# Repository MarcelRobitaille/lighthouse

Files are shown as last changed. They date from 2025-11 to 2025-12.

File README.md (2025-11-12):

# Lighthouse

> Lighthouse is a PCB that controls lights in my house.

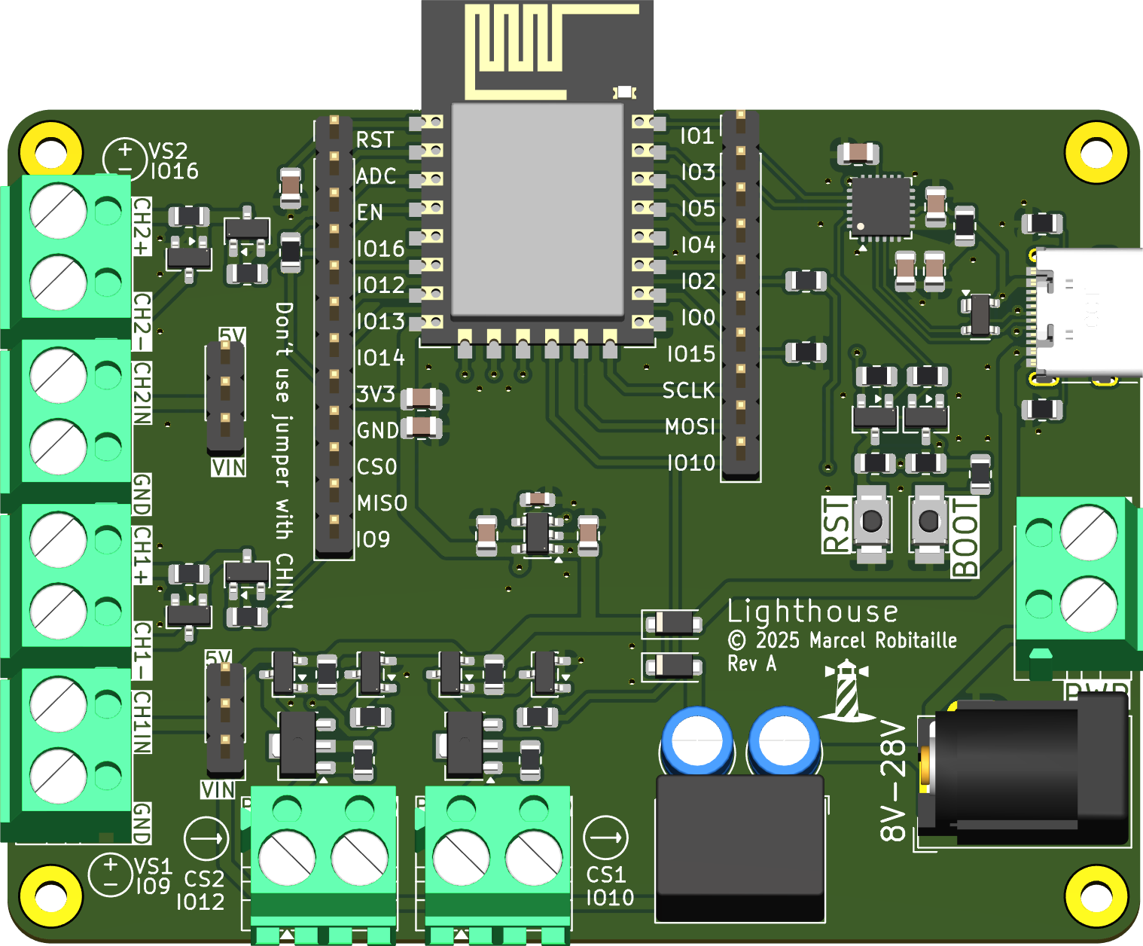
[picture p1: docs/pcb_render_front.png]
3D Render of the PCB


## Features

- ESP8266 module (works with ESPHome)
- Two constant voltage outputs and two constant current outputs
- Powered from USB-C, barrel, or screw terminal
- Voltage outputs can be powered separately, or from global USB/barrel/screw terminal

It's doesn't have to be for lighting, but any small load you wish to switch remotely.

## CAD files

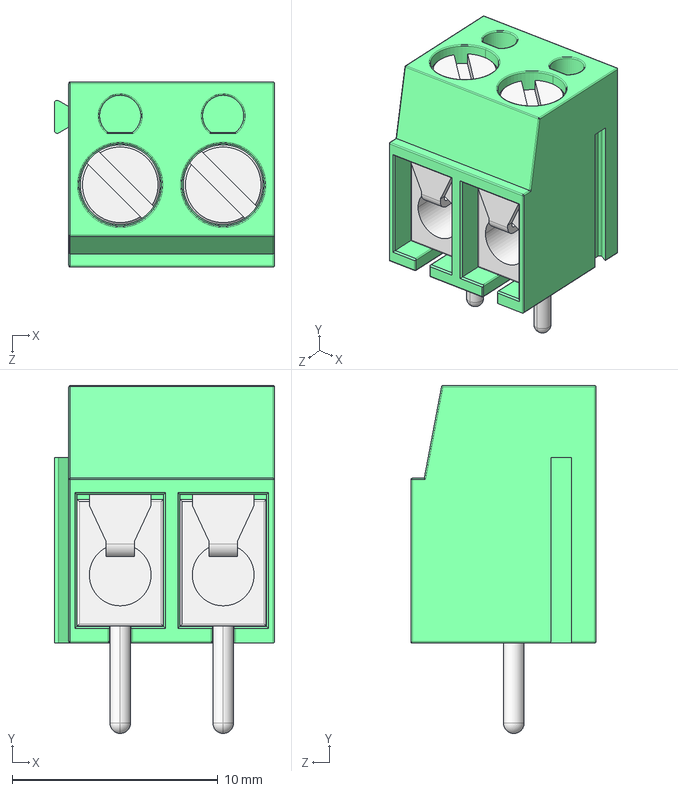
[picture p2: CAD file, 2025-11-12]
3d/TB0010-500-02GR.stp
10.7 x 16.9 x 9.00 mm

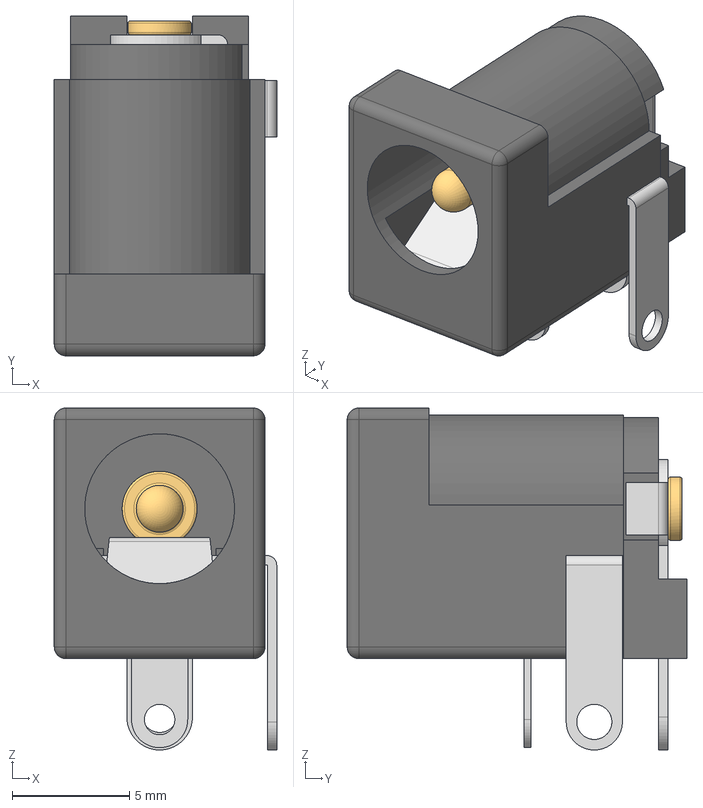
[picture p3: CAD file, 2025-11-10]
3d/694106301002 (rev1).stp
9.50 x 14.5 x 14.6 mm
6941xx301002
694106301002_PinContact
6941xx301002_Back
6941xx301002_PinContact2
6941xx301002_PinLame
6941xx301002_PinBis

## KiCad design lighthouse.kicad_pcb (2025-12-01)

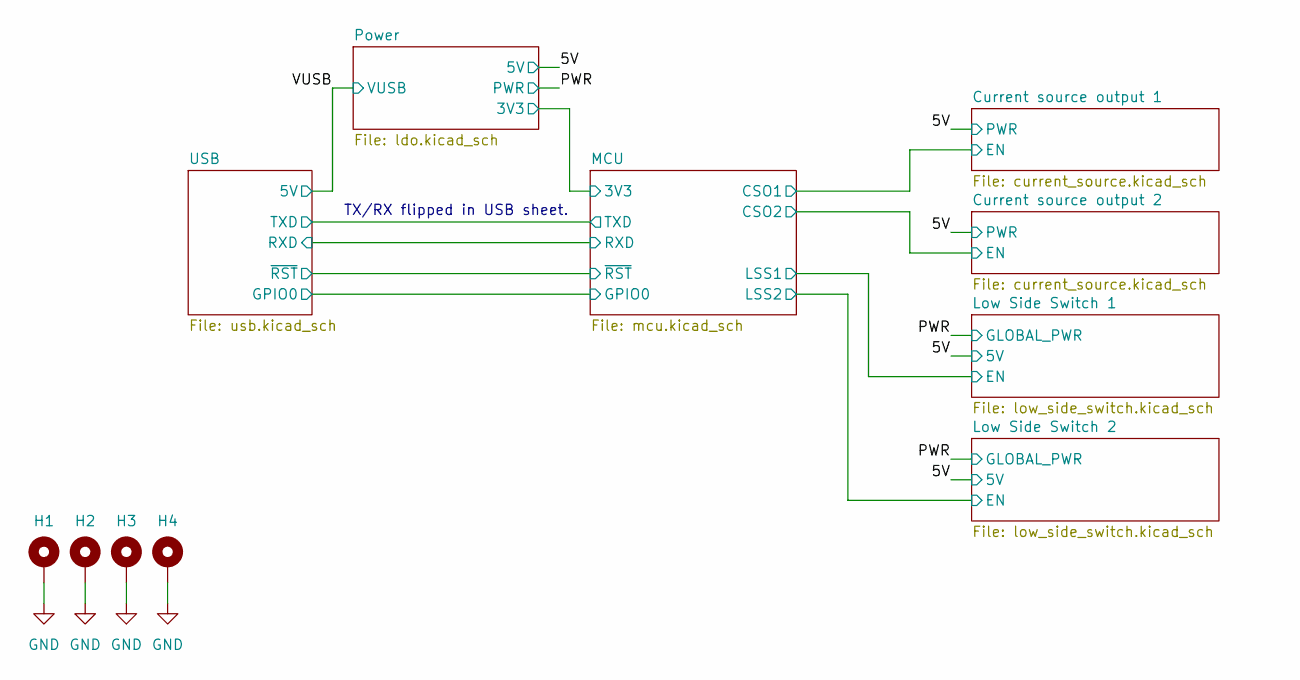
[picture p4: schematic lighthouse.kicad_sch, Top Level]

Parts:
H1, H2, H3, H4: MountingHole_Pad; MountingHole_2.2mm_M2_Pad

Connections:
GND: H1.1, H2.1, H3.1, H4.1; also elsewhere on the board

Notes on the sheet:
TX/RX flipped in USB sheet.

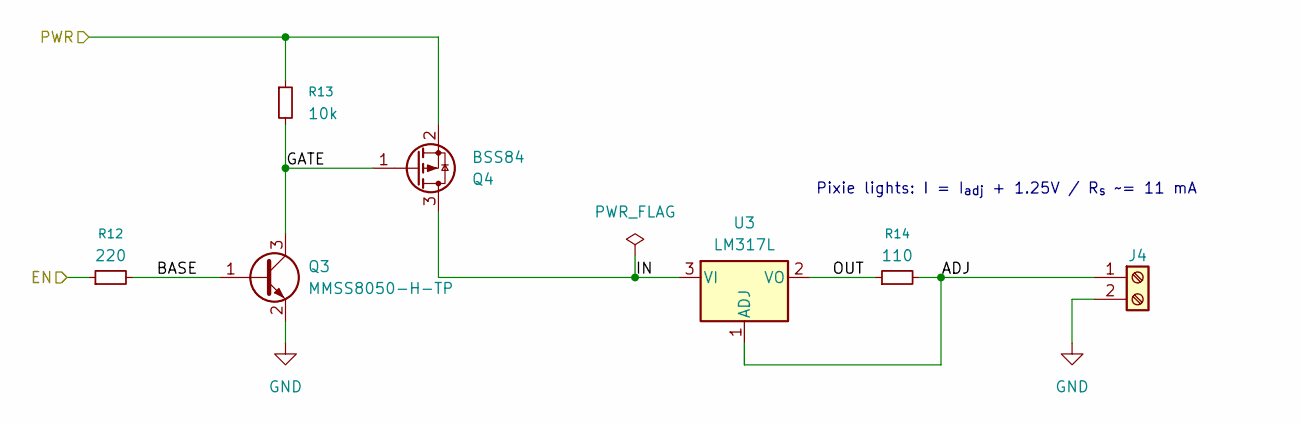
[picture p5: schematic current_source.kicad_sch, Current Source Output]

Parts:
J4: TB0010-500-02GR; TerminalBlock_TB0010-500-02GR_1x02_P5.00mm
Q3: MMSS8050-H-TP; SOT-23-3; MPN MMSS8050-H-TP; LCSC Part Number C2891804
Q4: BSS84; SOT-23; MPN BSS84PH6327XTSA2; Digikey Part Number BSS84PH6327XTSA2CT-ND
R12: 220; R_0805_2012Metric; MPN CRCW0805220RJNEA; Mouser Part Number 71-CRCW0805220RJNEA
R13: 10k; R_0805_2012Metric; Tolerance 5 %; MPN CRCW080510K0JNEAC; Mouser Part Number 71-CRCW080510K0JNEAC
R14: 110; R_0805_2012Metric; Tolerance 1%; MPN CRCW0805110RFKEA; Mouser Part Number 71-CRCW0805-110-E3
U3: LM317L; SOT-89-3; MPN LM317LCPK; Mouser Part Number 595-LM317LCPK

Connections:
/5V: Q4.2 (S), R13.1; also elsewhere on the board
/Current source output 2/ADJ: J4.1, R14.2, U3.1 (ADJ)
/Current source output 2/BASE: Q3.1 (B), R12.2
/Current source output 2/GATE: Q3.3 (C), Q4.1 (G), R13.2
/Current source output 2/IN: Q4.3 (D), U3.3 (VI)
/Current source output 2/OUT: R14.1, U3.2 (VO)
/MCU/CSO2: R12.1; also elsewhere on the board
GND: J4.2, Q3.2 (E); also elsewhere on the board

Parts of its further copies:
J7: TB0010-500-02GR; TerminalBlock_TB0010-500-02GR_1x02_P5.00mm
Q5: MMSS8050-H-TP; SOT-23-3; MPN MMSS8050-H-TP; LCSC Part Number C2891804
Q6: BSS84; SOT-23; MPN BSS84PH6327XTSA2; Digikey Part Number BSS84PH6327XTSA2CT-ND
R15: 220; R_0805_2012Metric; MPN CRCW0805220RJNEA; Mouser Part Number 71-CRCW0805220RJNEA
R16: 10k; R_0805_2012Metric; Tolerance 5 %; MPN CRCW080510K0JNEAC; Mouser Part Number 71-CRCW080510K0JNEAC
R17: 110; R_0805_2012Metric; Tolerance 1%; MPN CRCW0805110RFKEA; Mouser Part Number 71-CRCW0805-110-E3
U6: LM317L; SOT-89-3; MPN LM317LCPK; Mouser Part Number 595-LM317LCPK

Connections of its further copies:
/5V: Q6.2 (S), R16.1; also elsewhere on the board
/Current source output 1/ADJ: J7.1, R17.2, U6.1 (ADJ)
/Current source output 1/BASE: Q5.1 (B), R15.2
/Current source output 1/GATE: Q5.3 (C), Q6.1 (G), R16.2
/Current source output 1/IN: Q6.3 (D), U6.3 (VI)
/Current source output 1/OUT: R17.1, U6.2 (VO)
/MCU/CSO1: R15.1; also elsewhere on the board
GND: J7.2, Q5.2 (E); also elsewhere on the board

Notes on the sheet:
Pixie lights: I = I_{adj} + 1.25V / R_{s} ~= 11 mA

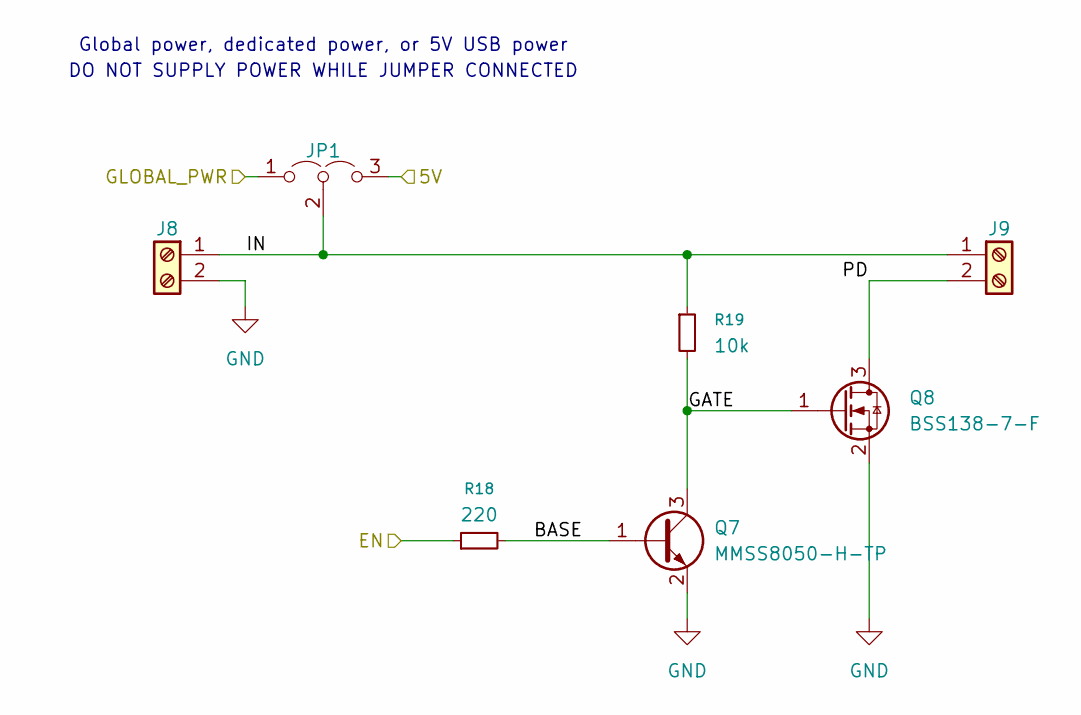
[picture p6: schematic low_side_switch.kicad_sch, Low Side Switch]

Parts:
J8, J9: TB0010-500-02GR; TerminalBlock_TB0010-500-02GR_1x02_P5.00mm
JP1: Jumper_3_Open; PinHeader_1x03_P2.54mm_Vertical
Q7: MMSS8050-H-TP; SOT-23-3; MPN MMSS8050-H-TP; LCSC Part Number C2891804
Q8: BSS138-7-F; SOT-23; MPN BSS138-7-F; Digikey Part Numbr BSS138-FDICT-ND
R18: 220; R_0805_2012Metric; MPN CRCW0805220RJNEA; Mouser Part Number 71-CRCW0805220RJNEA
R19: 10k; R_0805_2012Metric; Tolerance 5 %; MPN CRCW080510K0JNEAC; Mouser Part Number 71-CRCW080510K0JNEAC

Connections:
/5V: JP1.3 (B); also elsewhere on the board
/Low Side Switch 2/BASE: Q7.1 (B), R18.2
/Low Side Switch 2/GATE: Q7.3 (C), Q8.1 (G), R19.2
/Low Side Switch 2/IN: J8.1, J9.1, JP1.2 (C), R19.1
/Low Side Switch 2/PD: J9.2, Q8.3 (D)
/MCU/LSS2: R18.1; also elsewhere on the board
/PWR: JP1.1 (A); also elsewhere on the board
GND: J8.2, Q7.2 (E), Q8.2 (S); also elsewhere on the board

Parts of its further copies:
J10, J11: TB0010-500-02GR; TerminalBlock_TB0010-500-02GR_1x02_P5.00mm
JP2: Jumper_3_Open; PinHeader_1x03_P2.54mm_Vertical
Q9: MMSS8050-H-TP; SOT-23-3; MPN MMSS8050-H-TP; LCSC Part Number C2891804
Q10: BSS138-7-F; SOT-23; MPN BSS138-7-F; Digikey Part Numbr BSS138-FDICT-ND
R20: 220; R_0805_2012Metric; MPN CRCW0805220RJNEA; Mouser Part Number 71-CRCW0805220RJNEA
R21: 10k; R_0805_2012Metric; Tolerance 5 %; MPN CRCW080510K0JNEAC; Mouser Part Number 71-CRCW080510K0JNEAC

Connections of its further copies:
/5V: JP2.3 (B); also elsewhere on the board
/Low Side Switch 1/BASE: Q9.1 (B), R20.2
/Low Side Switch 1/GATE: Q9.3 (C), Q10.1 (G), R21.2
/Low Side Switch 1/IN: J10.1, J11.1, JP2.2 (C), R21.1
/Low Side Switch 1/PD: J11.2, Q10.3 (D)
/MCU/LSS1: R20.1; also elsewhere on the board
/PWR: JP2.1 (A); also elsewhere on the board
GND: J10.2, Q9.2 (E), Q10.2 (S); also elsewhere on the board

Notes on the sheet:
Global power, dedicated power, or 5V USB power
DO NOT SUPPLY POWER WHILE JUMPER CONNECTED

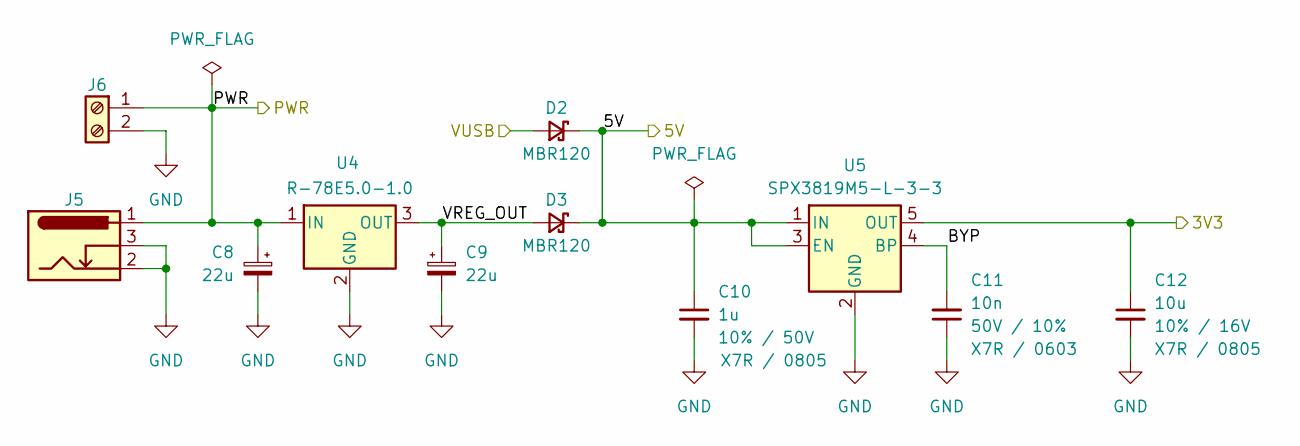
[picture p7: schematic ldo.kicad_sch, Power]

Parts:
C8, C9: 22u; C_Radial_D5.0mm_H5.0mm_P2.00mm
C10: 1u; C_0805_2012Metric; Tolerance 10%; Rated Voltage 50V; MPN CC0805KKX7R9BB105; LCSC Part Number C91185
C11: 10n; C_0603_1608Metric; Rated Voltage 50V; Tolerance 10%; MPN CC0603KRX7R9BB103; LCSC Part Number C100042
C12: 10u; C_0805_2012Metric; Rated Voltage 16V; Tolerance 10%; MPN CL21A106KOQNNNE; Mouser Part Number 187-CL21A106KOQNNNE
D2, D3: MBR120; D_SOD-123F; MPN MBR120ESFT1G; Mouser Part Number 863-MBR120ESFT1G
J5: 694106301002; BarrelJack_Wuerth_6941xx301002; MPN 694106301002; Digikey Part Number 732-5930-ND
J6: TB0010-500-02GR; TerminalBlock_TB0010-500-02GR_1x02_P5.00mm
U4: R-78E5.0-1.0; Converter_DCDC_RECOM_R-78E-0.5_THT; MPN R-78E5.0-1.0; Mouser Part Number 919-R-78E5.0-1.0
U5: SPX3819M5-L-3-3; SOT-23-5; MPN SPX3819M5-L-3-3/TR; LCSC Part Number C9055

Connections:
/5V: C10.1, D2.1 (K), D3.1 (K), U5.1 (IN), U5.3 (EN); also elsewhere on the board
/MCU/3V3: C12.1, U5.5 (OUT); also elsewhere on the board
/PWR: C8.1, J5.1, J6.1, U4.1 (IN); also elsewhere on the board
/Power/BYP: C11.2, U5.4 (BP)
/Power/VREG_OUT: C9.1, D3.2 (A), U4.3 (OUT)
/VUSB: D2.2 (A); also elsewhere on the board
GND: C8.2, C9.2, C10.2, C11.1, C12.2, J5.2, J5.3, J6.2, U4.2 (GND), U5.2 (GND); also elsewhere on the board

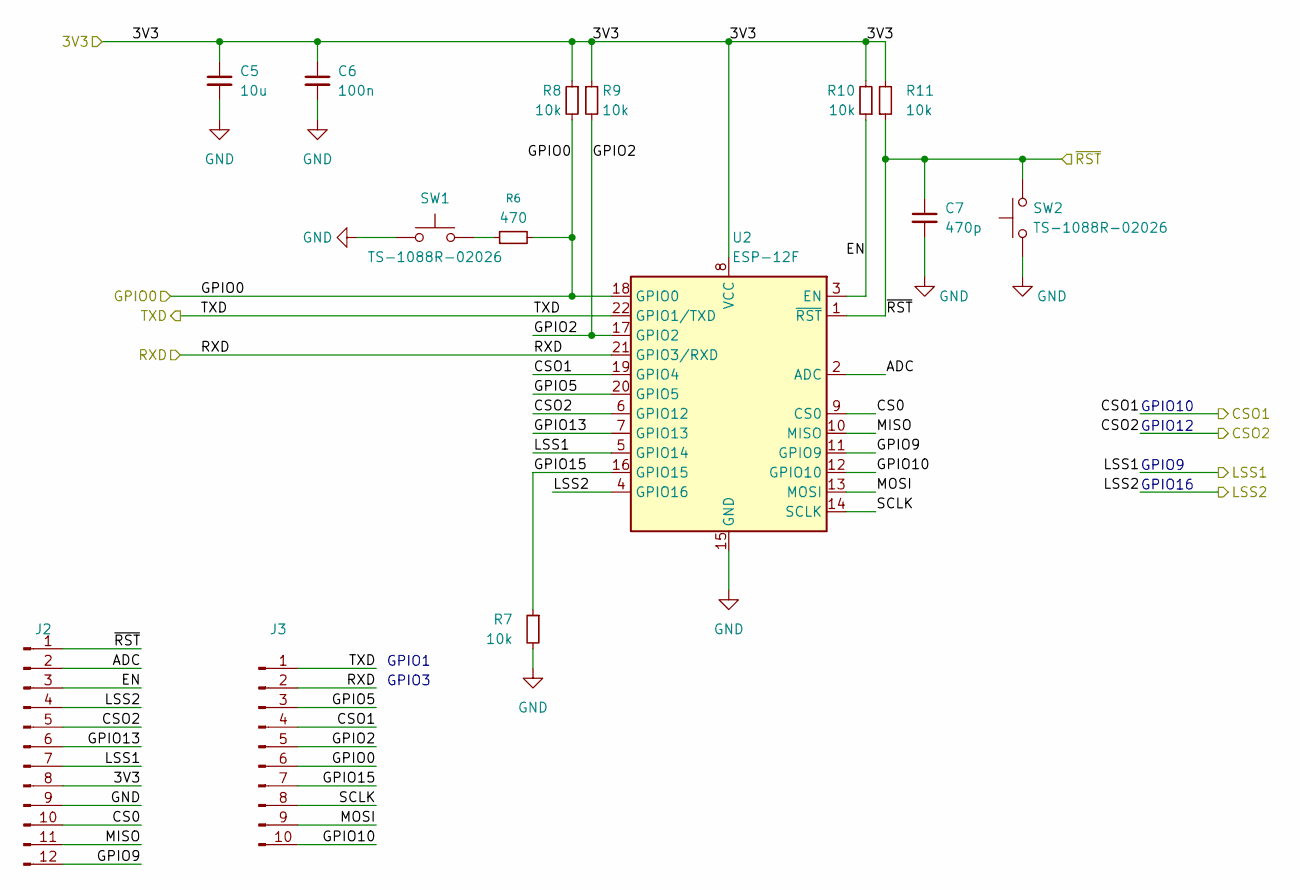
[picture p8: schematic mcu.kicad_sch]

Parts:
C5: 10u; C_0805_2012Metric; Rated Voltage 16V; Tolerance 10%; MPN CL21A106KOQNNNE; Mouser Part Number 187-CL21A106KOQNNNE
C6: 100n; C_0805_2012Metric; Rated Voltage 50V; Tolerance 10%; MPN 0805B104K500NT; LCSC Part Number C38141
C7: 470p; C_0805_2012Metric; MPN 885012007038; Mouser Part Number 710-885012007038
J2: Conn_01x05_Pin; PinHeader_1x12_P2.54mm_Vertical
J3: Conn_01x10_Pin; PinHeader_1x10_P2.54mm_Vertical
R6: 470; R_0805_2012Metric; Tolerance 1%; MPN CRCW0805470RFKEA; Mouser Part Number 71-CRCW0805-470-E3
R7, R8, R9, R10, R11: 10k; R_0805_2012Metric; Tolerance 5 %; MPN CRCW080510K0JNEAC; Mouser Part Number 71-CRCW080510K0JNEAC
SW1, SW2: TS-1088R-02026; TS-1088R-02026_SW_SMD_3x4mm; MPN TS-1088R-02026; LCSC Part Number C455280
U2: ESP-12F; ESP-12E; MPN ESP-12F(ESP8266MOD); LCSC Part Number C82891

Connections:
/MCU/3V3: C5.1, C6.1, J2.8, R8.1, R9.1, R10.2, R11.2, U2.8 (VCC); also elsewhere on the board
/MCU/ADC: J2.2, U2.2 (ADC)
/MCU/CS0: J2.10, U2.9 (CS0)
/MCU/CSO1: J3.4, U2.19 (GPIO4); also elsewhere on the board
/MCU/CSO2: J2.5, U2.6 (GPIO12); also elsewhere on the board
/MCU/EN: J2.3, R10.1, U2.3 (EN)
/MCU/GPIO0: J3.6, R6.2, R8.2, U2.18 (GPIO0); also elsewhere on the board
/MCU/GPIO2: J3.5, R9.2, U2.17 (GPIO2)
/MCU/GPIO5: J3.3, U2.20 (GPIO5)
/MCU/GPIO9: J2.12, U2.11 (GPIO9)
/MCU/GPIO10: J3.10, U2.12 (GPIO10)
/MCU/GPIO13: J2.6, U2.7 (GPIO13)
/MCU/GPIO15: J3.7, R7.1, U2.16 (GPIO15)
/MCU/LSS1: J2.7, U2.5 (GPIO14); also elsewhere on the board
/MCU/LSS2: J2.4, U2.4 (GPIO16); also elsewhere on the board
/MCU/MISO: J2.11, U2.10 (MISO)
/MCU/MOSI: J3.9, U2.13 (MOSI)
/MCU/RXD: J3.2, U2.21 (GPIO3/RXD); also elsewhere on the board
/MCU/SCLK: J3.8, U2.14 (SCLK)
/MCU/TXD: J3.1, U2.22 (GPIO1/TXD); also elsewhere on the board
/MCU/~RST: C7.1, J2.1, R11.1, SW2.2, U2.1 (~RST); also elsewhere on the board
GND: C5.2, C6.2, C7.2, J2.9, R7.2, SW1.2, SW2.1, U2.15 (GND); also elsewhere on the board
unnamed: R6.1, SW1.1

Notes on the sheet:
GPIO16
GPIO1
GPIO10
GPIO12
GPIO3
GPIO9

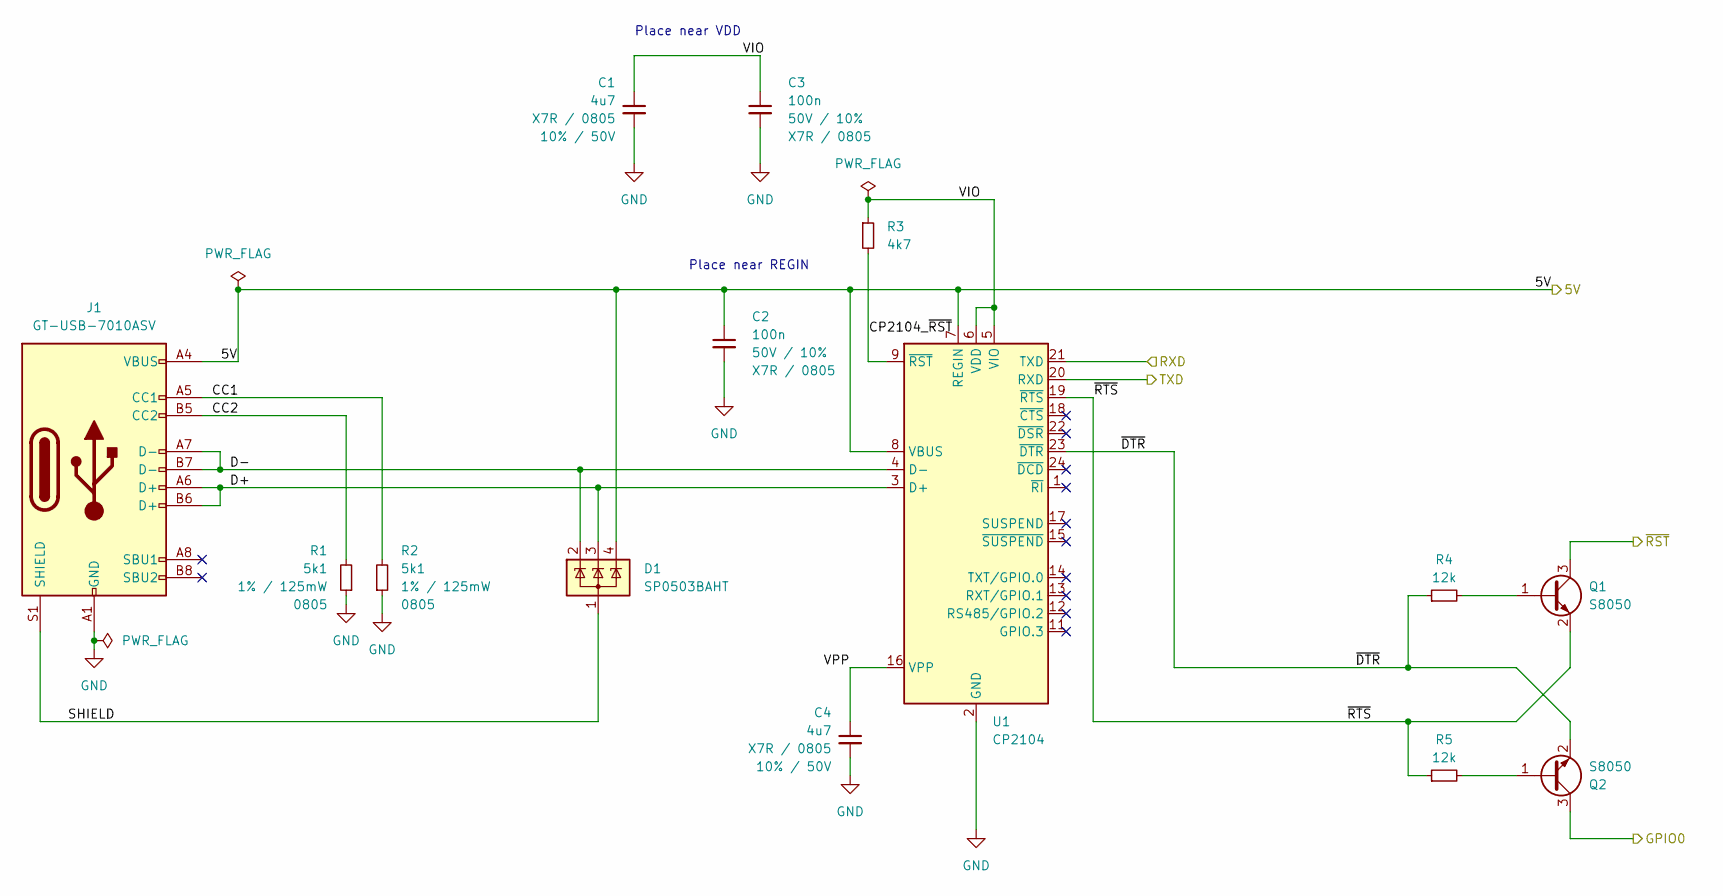
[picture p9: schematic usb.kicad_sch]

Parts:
C1, C4: 4u7; C_0805_2012Metric; Rated Voltage 50V; Tolerance 10%; MPN CL21A475KBQNNNE; LCSC Part Number C98192
C2, C3: 100n; C_0805_2012Metric; Rated Voltage 50V; Tolerance 10%; MPN 0805B104K500NT; LCSC Part Number C38141
D1: SP0503BAHT; SOT-143; MPN SP0503BAHTG; LCSC Part Number C7074
J1: GT-USB-7010ASV; USB_C_Receptacle_G-Switch_GT-USB-7010ASV; MPN G-Switch; LCSC Part Number C2988369
Q1, Q2: S8050; SOT-23-3; MPN MMSS8050-L-TP; Mouser Part Number 833-MMSS8050-L-TP
R1, R2: 5k1; R_0805_2012Metric; Tolerance 1%; MPN CRCW08055K10FKEAC; Mouser Part Number 71-CRCW08055K10FKEAC
R3: 4k7; R_0805_2012Metric; Tolerance 1%; MPN CR0805-FX-4701ELF; Mouser Part Number 652-CR0805FX-4701ELF
R4, R5: 12k; R_0805_2012Metric; Tolerance 1%; MPN CRCW080512K0JNEA; Mouser Part Number 71-CRCW080512K0JNEA
U1: CP2104; QFN-24-1EP_4x4mm_P0.5mm_EP2.6x2.6mm; MPN CP2104-F03-GMR; LCSC Part Number C47742

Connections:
/MCU/GPIO0: Q2.3 (C); also elsewhere on the board
/MCU/RXD: U1.21 (TXD); also elsewhere on the board
/MCU/TXD: U1.20 (RXD); also elsewhere on the board
/MCU/~RST: Q1.3 (C); also elsewhere on the board
/USB/CC1: J1.A5 (CC1), R2.2
/USB/CC2: J1.B5 (CC2), R1.2
/USB/CP2104_~RST: R3.2, U1.9 (~RST)
/USB/D+: D1.3 (K), J1.A6 (D+), J1.B6 (D+), U1.3 (D+)
/USB/D-: D1.2 (K), J1.A7 (D-), J1.B7 (D-), U1.4 (D-)
/USB/SHIELD: D1.1 (A), J1.S1 (SHIELD)
/USB/VIO: C1.1, C3.1, R3.1, U1.5 (VIO), U1.6 (VDD)
/USB/VPP: C4.1, U1.16 (VPP)
/USB/~DTR: Q2.2 (E), R4.1, U1.23 (~DTR)
/USB/~RTS: Q1.2 (E), R5.1, U1.19 (~RTS)
/VUSB: C2.1, D1.4 (K), J1.A4 (VBUS), J1.A9 (VBUS), J1.B4 (VBUS), J1.B9 (VBUS), U1.7 (REGIN), U1.8 (VBUS); also elsewhere on the board
GND: C1.2, C2.2, C3.2, C4.2, J1.A1 (GND), J1.A12 (GND), J1.B1 (GND), J1.B12 (GND), R1.1, R2.1, U1.2 (GND), U1.25 (GND); also elsewhere on the board
unnamed: Q1.1 (B), R4.2
unnamed: Q2.1 (B), R5.2

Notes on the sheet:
Place near VDD
Place near REGIN

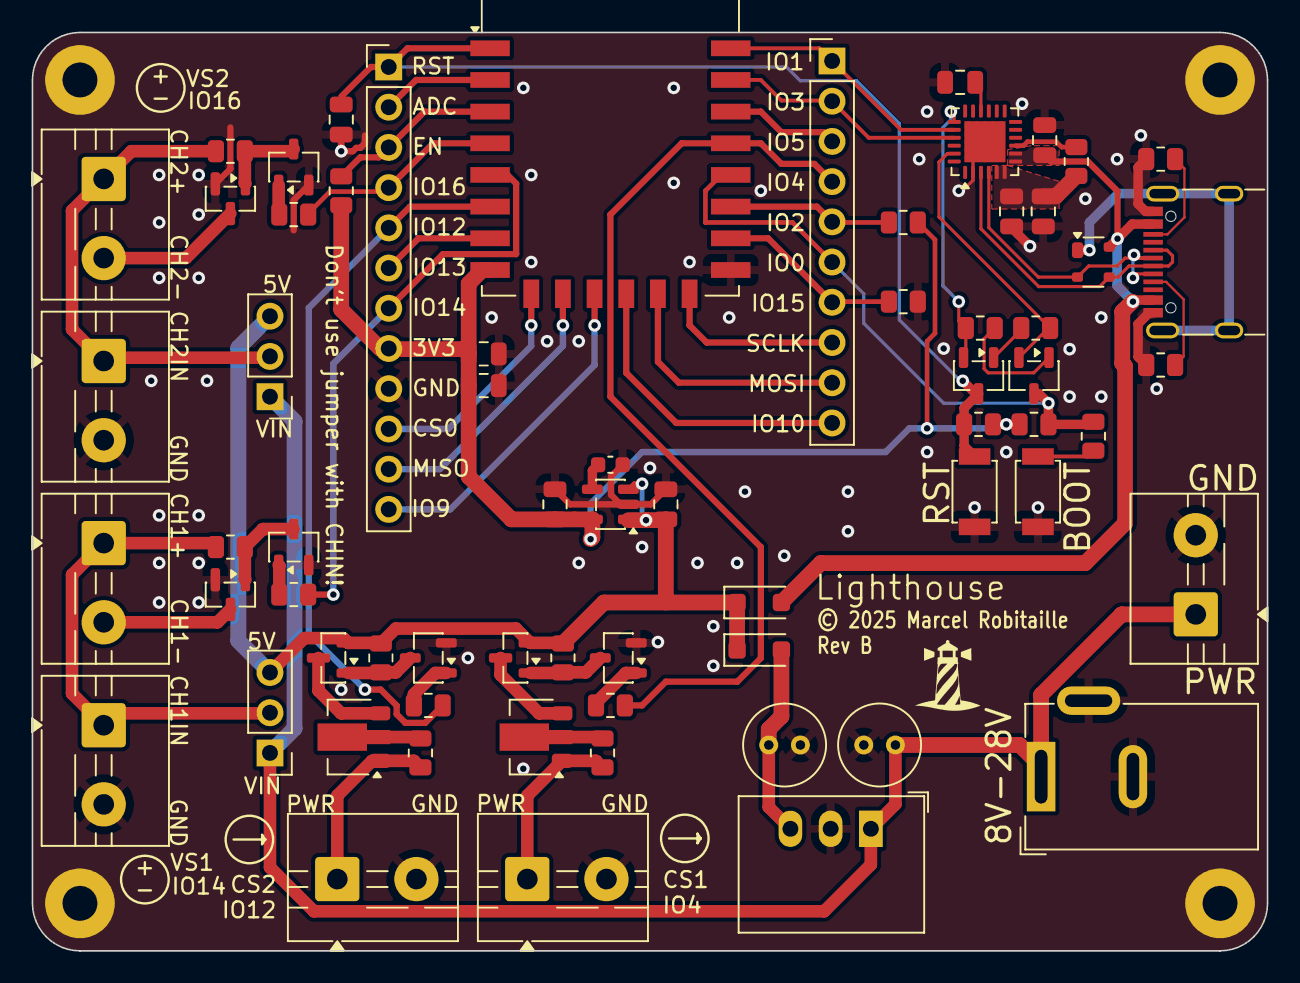
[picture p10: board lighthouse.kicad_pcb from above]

Board: 2 copper layers, 78.0 x 58.0 mm, 71 parts (0 on the bottom side), 58 nets.

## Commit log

2025-09-15 Update to kicad 9
    [epd.kicad_sch, ldo.kicad_sch, mcu.kicad_sch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]
2025-09-15 Fix hardware flow control transistor pinouts
    [usb.kicad_sch]
2025-09-15 Fix using same GPIO for epd D/C and boot
    [mcu.kicad_sch]
2025-09-15 Update reference designators to single digit
    Fits on the silk better
    [epd.kicad_sch, ldo.kicad_sch, mcu.kicad_sch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]
2025-09-15 Update layout and routing
    [youdbetterrun.kicad_pcb]
2025-11-12 Ignore additional footprint
2025-11-12 Termianl block 3d view
    [TB0010-500-02GR.stp, current_source.kicad_sch, ldo.kicad_sch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]
2025-11-16 Add component attributes
    [current_source.kicad_sch, ldo.kicad_sch, lighthouse.kicad_sch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]
2025-12-01 Correct unusable FLASH SPI pins
    [lighthouse.kicad_pcb, mcu.kicad_sch]

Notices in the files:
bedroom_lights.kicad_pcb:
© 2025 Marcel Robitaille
